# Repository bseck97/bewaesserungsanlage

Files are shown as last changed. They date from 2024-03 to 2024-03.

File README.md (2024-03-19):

# Automatische Bewässerungsanlage

## Beschreibung

Automatische Bewässerungsanlage bestehend aus einer Basisstation mit einem ESP32 und kapazitiven Bodenfeuchtesensoren.

Die Bewässerungsanlage ist im Rahmen eines Masterprojekts der [Hochschule Heilbronn](https://www.hs-heilbronn.de/) entstanden. Die Entwicklung und die Messungen fanden im Labor für Elektronische Schaltungstechnik statt. 

Für weitere Informationen wird auf die [Dokumentation](./dokumentation.pdf) verwiesen. 

## Dateistruktur

- basisstation - ESP-IDF Projekt für die Basisstation
- sensor - STM32CubeMX Projekt für den Sensor
- sensor_pcb - EAGLE Projekt für das Sensorboard

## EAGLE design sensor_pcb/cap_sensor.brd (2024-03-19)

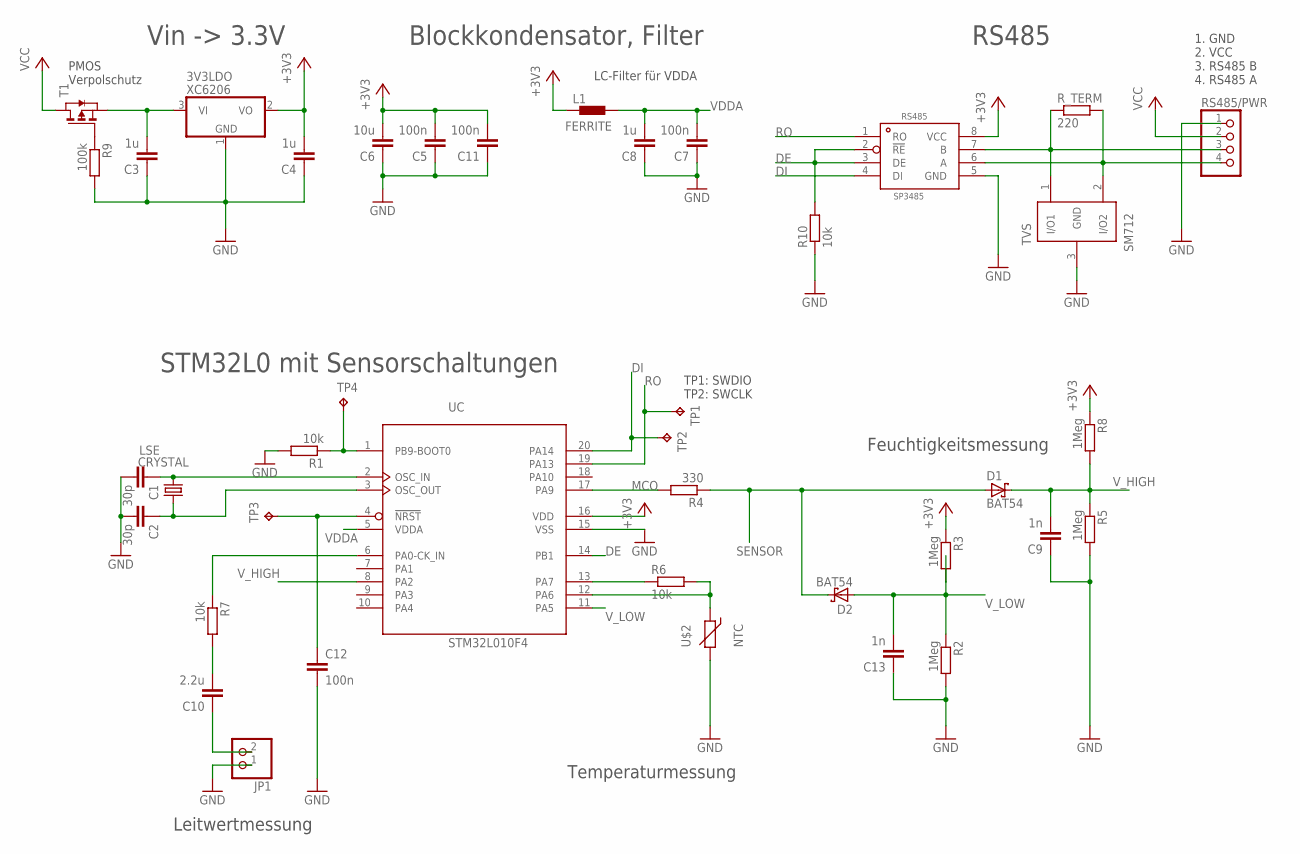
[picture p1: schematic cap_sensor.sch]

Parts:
3V3LDO: XC6206; SOT23-3
C1, C2: 30p; C0603
C3, C4, C8: 1u; C0603
C5, C7, C11, C12: 100n; C0603
C6: 10u; C0603
C9, C13: 1n; C0603
C10: 2.2u; C0603
D1, D2: BAT54; SOT23
JP1: PINHD-1X2; 1X02
L1: FERRITE; R0603
LSE: CRYSTAL; CRYSTAL-3.2X1.5
R1, R6, R7, R10: 10k; R0603
R2, R3, R5, R8: 1Meg; R0603
R4: 330; R0603
R9: 100k; R0603
RS485: SP3485; NSOIC8
RS485/PWR: PINHD-1X4; 1X04
R_TERM: 220; R0603
T1: PMOSSOT23; SOT-23
TP1, TP2, TP3, TP4: TPTP12R; TP12R
TVS: SM712; SOT23-3
U$2: NTC; R0603
UC: STM32L010F4; TSSOP20-I

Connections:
+3V3: 3V3LDO.2 (VO), C4.2, C5.2, C6.2, C11.2, L1.1, R3.1, R8.1, RS485.8 (VCC), UC.16 (VDD)
DE: R10.2, RS485.2 (!RE), RS485.3 (DE), UC.14 (PB1)
DI: RS485.4 (DI), TP2.TP, UC.20 (PA14)
GND: 3V3LDO.1 (GND), C1.2, C2.2, C3.1, C4.1, C5.1, C6.1, C7.1, C8.1, C9.1, C11.1, C12.2, C13.1, JP1.1, R1.2, R2.2, R5.2, R9.2, R10.1, RS485.5 (GND), RS485/PWR.1, TVS.3 (GND), U$2.2, UC.15 (VSS)
MCO: R4.2, UC.17 (PA9)
unnamed: 3V3LDO.3 (VI), C3.2, T1.2 (S)
unnamed: R1.1, TP4.TP, UC.1 (PB9-BOOT0)
unnamed: R6.1, UC.13 (PA7)
unnamed: C10.1, JP1.2
unnamed: C10.2, R7.2
unnamed: R6.2, U$2.1, UC.12 (PA6)
unnamed: C12.1, TP3.TP, UC.4 (!NRST)
unnamed: C1.1, LSE.1, UC.2 (OSC_IN)
unnamed: C2.1, LSE.2, UC.3 (OSC_OUT)
unnamed: R9.1, T1.3 (G)
unnamed: RS485.7 (B), RS485/PWR.3, R_TERM.1, TVS.1 (I/O1)
unnamed: RS485.6 (A), RS485/PWR.4, R_TERM.2, TVS.2 (I/O2)
RO: RS485.1 (RO), TP1.TP, UC.19 (PA13)
SENSOR: D1.1 (A), D2.3 (C), R4.1
SENS_RES: R7.1, UC.6 (PA0-CK_IN)
VCC: RS485/PWR.2, T1.1 (D)
VDDA: C7.2, C8.2, L1.2, UC.5 (VDDA)
V_HIGH: C9.2, D1.3 (C), R5.1, R8.2, UC.8 (PA2)
V_LOW: C13.2, D2.1 (A), R2.1, R3.2, UC.11 (PA5)

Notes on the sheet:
LC-Filter für VDDA
TP1: SWDIO TP2: SWCLK
PMOS Verpolschutz
Blockkondensator, Filter
Leitwertmessung
Feuchtigkeitsmessung
Temperaturmessung
Vin -> 3.3V
RS485
STM32L0 mit Sensorschaltungen
1. GND 2. VCC 3. RS485 B 4. RS485 A

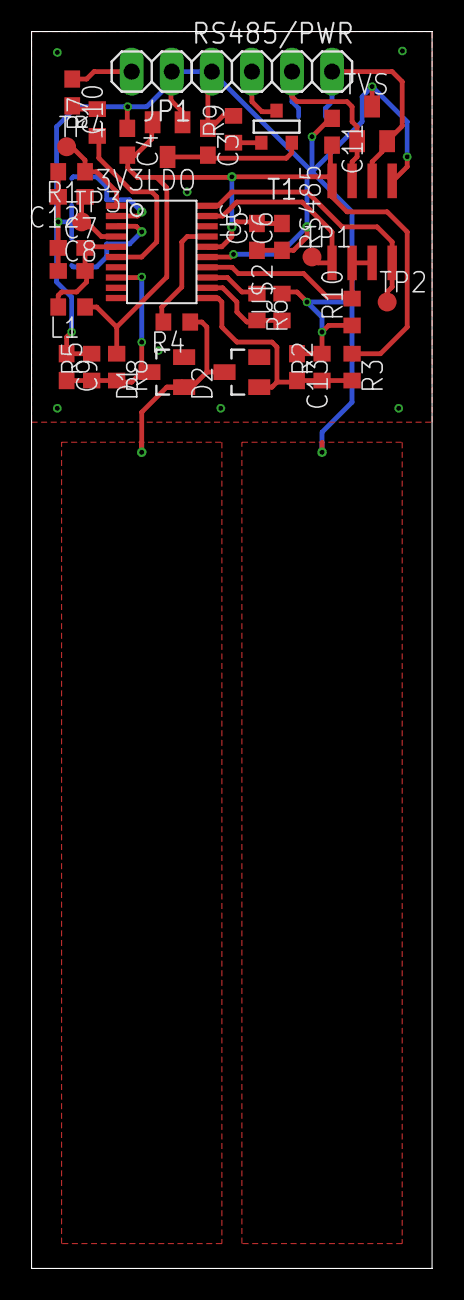
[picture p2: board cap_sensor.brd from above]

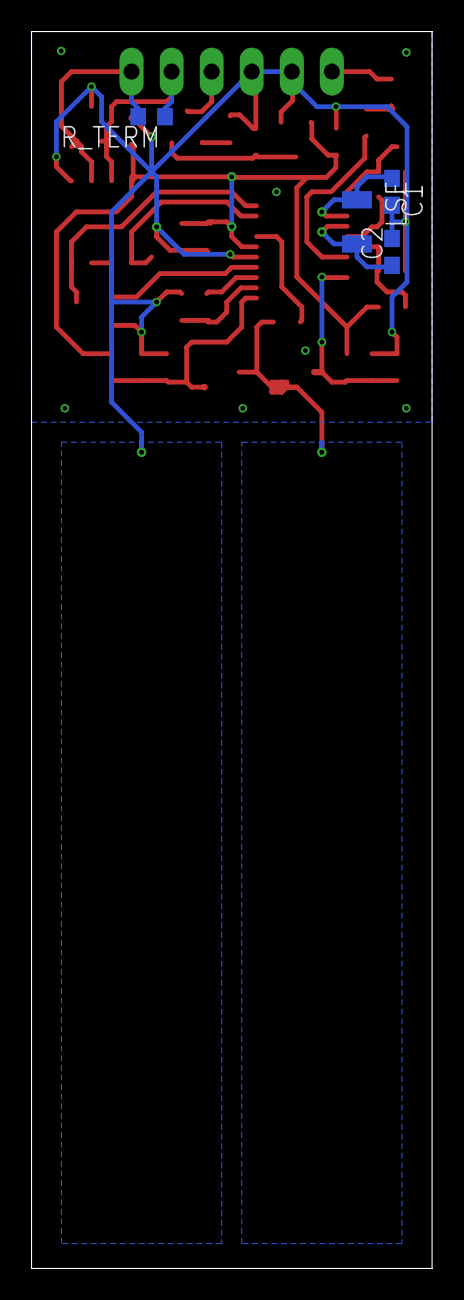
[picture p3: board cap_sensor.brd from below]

Board: 2 copper layers, 25.4 x 78.4 mm, 40 parts (4 on the bottom side), 24 nets.

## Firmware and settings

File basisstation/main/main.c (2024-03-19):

#include "driver/uart.h"
#include "esp_log.h"
#include "esp_system.h"
#include "esp_vfs_fat.h"
#include "freertos/FreeRTOS.h"
#include "freertos/queue.h"
#include "freertos/task.h"
#include "nvs_flash.h"
#include "sdkconfig.h"
#include "sdmmc_cmd.h"
#include <stdio.h>
#include <stdlib.h>
#include <string.h>
#include <sys/stat.h>
#include <sys/unistd.h>
// WIFI
#include "esp_event.h"
#include "esp_wifi.h"
#include "freertos/event_groups.h"
#include "lwip/err.h"
#include "lwip/sys.h"
#include "nvs_flash.h"
// NTP Time
#include "esp_sntp.h"
#include "time.h"
// timer
#include "esp_timer.h"
// MQTT
#include "cJSON.h"
#include "mqtt_client.h"
// steinhart-hart
#include <math.h>

#define TAG "ESP32_BASIS"

/* MQTT */
#define MQTT_URI "mqtt://MQTT_HOST_IP"
// topics
#define SENSOR_DATA "/topic/sensor"
#define DEBUG_MSG "/topic/debug"
#define THRESHOLD_TOPIC "/topic/threshold"
#define SENSOR_COUNT_TOPIC "/topic/sensor_count"
#define SENSOR_THRESHOLD_TOPIC "/topic/sensor_threshold"
#define PUMP_ON_TIME_TOPIC "/topic/pump_on_time"
#define PUMP_ON_TOPIC "/topic/pump_on"
#define SEND_ID_DELAY_TOPIC "/topic/send_id_delay"
#define TX_TASK_DELAY_TOPIC "/topic/tx_task_delay"
#define SENSOR_DATA_TOPIC "/topic/sensor_data"

esp_mqtt_client_handle_t client;
bool mqtt_connected = false; // flag to check if mqtt is connected

/* WIFI */
#define WIFI_SSID "YOUR_WIFI_SSID"
#define WIFI_PASSWORD "YOUR_WIFI_PASSWORD"

static EventGroupHandle_t
    s_wifi_event_group; // FreeRTOS event group to signal when we are connected
static int s_retry_num = 0;     // number of retries to connect to wifi
#define WIFI_CONNECTED_BIT BIT0 // connected to the AP with an IP
#define WIFI_FAIL_BIT                                                          \
  BIT1 // failed to connect after the maximum amount of retries

/* SD CARD */
#define MOUNT_POINT "/sdcard"
#define FILE_NAME MOUNT_POINT "/data.txt"

#define PIN_NUM_MISO 19
#define PIN_NUM_MOSI 23
#define PIN_NUM_CLK 18
#define PIN_NUM_CS 5

/* UART */
#define TXD 17
#define RXD 16
#define RTS 4
#define CTS -1 // CTS is not used in RS485 Half-Duplex Mode

#define DATA_LENGTH 20
#define RX_BUF_SIZE (127)
#define BAUD_RATE 115200
#define UART_PORT 2
// Read packet timeout
#define PACKET_READ_TICS (1000 / portTICK_PERIOD_MS)
// Timeout threshold for UART = number of symbols (~10 tics) with unchanged
// state on receive pin
#define READ_TOUT (3) // 3.5T * 8 = 28 ticks, TOUT=3 -> ~24..33 ticks

/* CONSTANTS AND OTHER CONFIG DATA */
#define LOG_TO_SD_CARD 1 // 1 to log data to SD card, 0 to disable
#define INIT_WIFI 1      // 1 to initialize wifi, 0 to disable
#define STACK_SIZE (2048)
#define REFERENCE_VOLTAGE 3.3
#define MAX_SENSORS 5
#define GPIO_PUMP 21           // GPIO to control relais
#define SECOND_US 1000000      // in microseconds
#define MINUTE_US 60 * 1000000 // in microseconds
#define MINUTE_MS 60 * 1000    // in milliseconds

// config vars, can be modified over MQTT
typedef struct {
  double threshold;
  int sensor_threshold;
  int sensor_count;
  int pump_on_time;
  int send_id_delay;
  int tx_task_delay;
} Config;

Config config = {
    .threshold = 2.0, // threshold after which the pump is turned on
    .sensor_threshold =
        2, // number of sensors that need to be above threshold to turn on pump
    .sensor_count = 3,             // number of sensors connected to the ESP32
    .pump_on_time = 5 * SECOND_US, // in microseconds, 5 seconds
    .send_id_delay = 3000,         // delay between sending IDs in ms (3s)
    .tx_task_delay =
        10 *
        MINUTE_MS // delay after another measurement set is taken in ms (10min)
};

// sensor data
typedef struct {
  uint32_t ID;
  double resistance_measurement_voltage;
  double V_HIGH_voltage;
  double V_LOW_voltage;
  double temperature;
} SensorData;

// history of sensor readings
typedef struct {
  SensorData current;
  SensorData previous1;
  SensorData previous2;
} SensorHistory;

SensorHistory
    sensorHistories[MAX_SENSORS]; // global var, all fields are init as 0

// timer to control pump on time
esp_timer_handle_t on_timer;

// task handles
TaskHandle_t rx_task_handle;
TaskHandle_t tx_task_handle;
TaskHandle_t sensordata_task_handle;

/* Function prototypes */
void uart_init(void);
void sd_card_init(void);
void initialize_sntp(void);
void wifi_init_sta(void);
void mqtt_init(void);

static void event_handler(void *arg, esp_event_base_t event_base,
                          int32_t event_id, void *event_data);
static void mqtt_event_handler(void *handler_args, esp_event_base_t base,
                               int32_t event_id, void *event_data);
static void on_timer_callback(void *arg);

esp_err_t send_ID(const int port, uint32_t id);
SensorData Convert_Bytes_to_Decimal(uint8_t *data);
double v_to_temp(double v_ntc);
char *sensor_data_to_json(const SensorData *data, bool include_time);
void write_to_sd_card(SensorData data);

static void tx_task(void *arg);
static void rx_task(void *arg);
static void sensordata_task(void *arg);

void app_main(void) {
  // create timer to turn off pump after pump_on_time
  const esp_timer_create_args_t on_timer_args = {.callback = &on_timer_callback,
                                                 .name = "on-timer"};
  ESP_ERROR_CHECK(esp_timer_create(&on_timer_args, &on_timer));

  // set PUMP GPIO to output
  gpio_set_direction(GPIO_PUMP, GPIO_MODE_OUTPUT);
  // set GPIO to LOW and turn off pump during init
  // in case the pump was on before restart
  gpio_set_level(GPIO_PUMP, 0);

  // check if INIT_WIFI is true, if not skip init
  if (INIT_WIFI) {
    // Initialize NVS, needed for WiFi
    esp_err_t ret = nvs_flash_init();
    if (ret == ESP_ERR_NVS_NO_FREE_PAGES ||
        ret == ESP_ERR_NVS_NEW_VERSION_FOUND) {
      ESP_ERROR_CHECK(nvs_flash_erase());
      ret = nvs_flash_init();
    }
    ESP_ERROR_CHECK(ret);

    wifi_init_sta();

    // if successfully connected, initialize SNTP and MQTT
    if (s_wifi_event_group != NULL) {
      if (xEventGroupGetBits(s_wifi_event_group) & WIFI_CONNECTED_BIT) {
        initialize_sntp();
        mqtt_init();
      }
    }
  }

  // check if LOG_TO_SD_CARD is true, if not skip init
  if (LOG_TO_SD_CARD) {
    sd_card_init();
  }

  uart_init();

  // wait a bit before starting the tasks
  vTaskDelay(2000 / portTICK_PERIOD_MS);

  // rx task gets double the default stack size, since fprintf uses a lot of
  // stack space
  xTaskCreate(rx_task, "uart_rx_task", STACK_SIZE * 2, NULL,
              configMAX_PRIORITIES, &rx_task_handle);
  xTaskCreate(tx_task, "uart_tx_task", STACK_SIZE, NULL,
              configMAX_PRIORITIES - 1, &tx_task_handle);
  xTaskCreate(sensordata_task, "sensordata_task", STACK_SIZE, NULL,
              configMAX_PRIORITIES - 2, &sensordata_task_handle);

  // this part is commented out by default, but can be used to check the stack
  // size of the tasks
  /*
  while (1)
  {
      UBaseType_t uxHighWaterMark = uxTaskGetStackHighWaterMark(rx_task_handle);
      ESP_LOGI(TAG, "Minimum free stack size for rx_task: %u", uxHighWaterMark);

      uxHighWaterMark = uxTaskGetStackHighWaterMark(tx_task_handle);
      ESP_LOGI(TAG, "Minimum free stack size for tx_task: %u", uxHighWaterMark);

      uxHighWaterMark = uxTaskGetStackHighWaterMark(sensordata_task_handle);
      ESP_LOGI(TAG, "Minimum free stack size for sensor readings task: %u",
  uxHighWaterMark);

      vTaskDelay(3000 / portTICK_PERIOD_MS);
  }
  */
}

static void on_timer_callback(void *arg) {
  // this is called after the timer expires
  // turn off pump
  gpio_set_level(GPIO_PUMP, 0); // Set GPIO to LOW
}

static void event_handler(void *arg, esp_event_base_t event_base,
                          int32_t event_id, void *event_data) {
  // wifi event handler
  if (event_base == WIFI_EVENT && event_id == WIFI_EVENT_STA_START) {
    esp_wifi_connect();
  } else if (event_base == WIFI_EVENT &&
             event_id == WIFI_EVENT_STA_DISCONNECTED) {
    if (s_retry_num < 5) {
      esp_wifi_connect();
      s_retry_num++;
      ESP_LOGI(TAG, "Retry to connect to the AP");
    } else {
      xEventGroupSetBits(s_wifi_event_group, WIFI_FAIL_BIT);
    }
    ESP_LOGI(TAG, "Connect to the AP fail");
  } else if (event_base == IP_EVENT && event_id == IP_EVENT_STA_GOT_IP) {
    ip_event_got_ip_t *event = (ip_event_got_ip_t *)event_data;
    ESP_LOGI(TAG, "Got IP:" IPSTR, IP2STR(&event->ip_info.ip));
    s_retry_num = 0;
    xEventGroupSetBits(s_wifi_event_group, WIFI_CONNECTED_BIT);
  }
}

static void mqtt_event_handler(void *handler_args, esp_event_base_t base,
                               int32_t event_id, void *event_data) {
  ESP_LOGD(TAG,
           "Event dispatched from event loop base=%s, event_id=%" PRIi32 "",
           base, event_id);
  esp_mqtt_event_handle_t event = event_data;
  client = event->client;

  switch ((esp_mqtt_event_id_t)event_id) {
  case MQTT_EVENT_CONNECTED:
    ESP_LOGI(TAG, "MQTT_EVENT_CONNECTED");
    mqtt_connected = true;

    // subscribe to topics
    esp_mqtt_client_subscribe(client, THRESHOLD_TOPIC, 0);
    esp_mqtt_client_subscribe(client, SENSOR_COUNT_TOPIC, 0);
    esp_mqtt_client_subscribe(client, PUMP_ON_TIME_TOPIC, 0);
    esp_mqtt_client_subscribe(client, PUMP_ON_TOPIC, 0);
    esp_mqtt_client_subscribe(client, SEND_ID_DELAY_TOPIC, 0);
    esp_mqtt_client_subscribe(client, TX_TASK_DELAY_TOPIC, 0);
    esp_mqtt_client_subscribe(client, SENSOR_THRESHOLD_TOPIC, 0);
    esp_mqtt_client_subscribe(client, SENSOR_DATA_TOPIC, 0);

    break;
  case MQTT_EVENT_DISCONNECTED:
    ESP_LOGI(TAG, "MQTT_EVENT_DISCONNECTED");
    mqtt_connected = false;
    break;
  case MQTT_EVENT_SUBSCRIBED:
    ESP_LOGI(TAG, "MQTT_EVENT_SUBSCRIBED, msg_id=%d", event->msg_id);
    break;
  case MQTT_EVENT_UNSUBSCRIBED:
    ESP_LOGI(TAG, "MQTT_EVENT_UNSUBSCRIBED, msg_id=%d", event->msg_id);
    break;
  case MQTT_EVENT_PUBLISHED:
    ESP_LOGI(TAG, "MQTT_EVENT_PUBLISHED, msg_id=%d", event->msg_id);
    break;
  case MQTT_EVENT_DATA:
    ESP_LOGI(TAG, "MQTT_EVENT_DATA");
    printf("TOPIC=%.*s\r\n", event->topic_len, event->topic);
    printf("DATA=%.*s\r\n", event->data_len, event->data);

    // Null-terminate the topic and data strings for easy handling
    char *topic = malloc(event->topic_len + 1);
    memcpy(topic, event->topic, event->topic_len);
    topic[event->topic_len] = '\0';

    char *data = malloc(event->data_len + 1);
    memcpy(data, event->data, event->data_len);
    data[event->data_len] = '\0';

    // Update configuration variables based on the topic
    if (strcmp(topic, THRESHOLD_TOPIC) == 0) {
      config.threshold = atof(data);
      ESP_LOGI(TAG, "New threshold: %f", config.threshold);
      esp_mqtt_client_publish(client, DEBUG_MSG, "threshold_updated", 0, 0, 0);
    } else if (strcmp(topic, PUMP_ON_TIME_TOPIC) == 0) {
      config.pump_on_time = atoi(data);
      ESP_LOGI(TAG, "New pump on time: %d", config.pump_on_time);
      esp_mqtt_client_publish(client, DEBUG_MSG, "pump_on_time_updated", 0, 0,
                              0);
    } else if (strcmp(topic, PUMP_ON_TOPIC) == 0) {
      gpio_set_level(GPIO_PUMP, 1);
      // Try to start the on_timer
      esp_err_t ret = esp_timer_start_once(on_timer, config.pump_on_time);
      if (ret != ESP_OK) {
        gpio_set_level(GPIO_PUMP, 0); // Turn off the pump immediately
        char error_message[100];      // Buffer for the error message
        snprintf(error_message, sizeof(error_message),
                 "Failed to start on_timer with error %d", ret);
        ESP_LOGE(TAG, "%s", error_message);

        // Publish the error via MQTT
        esp_mqtt_client_publish(client, DEBUG_MSG, error_message, 0, 0, 0);
      } else {
        esp_mqtt_client_publish(client, DEBUG_MSG, "pump_on", 0, 0, 0);
      }
    } else if (strcmp(topic, SENSOR_COUNT_TOPIC) == 0) {
      config.sensor_count = atoi(data);
      ESP_LOGI(TAG, "New sensor count: %d", config.sensor_count);
      esp_mqtt_client_publish(client, DEBUG_MSG, "sensor_count_updated", 0, 0,
                              0);
    } else if (strcmp(topic, SEND_ID_DELAY_TOPIC) == 0) {
      config.send_id_delay = atoi(data);
      ESP_LOGI(TAG, "New send id delay: %d", config.send_id_delay);
      esp_mqtt_client_publish(client, DEBUG_MSG, "send_id_delay_updated", 0, 0,
                              0);
    } else if (strcmp(topic, TX_TASK_DELAY_TOPIC) == 0) {
      config.tx_task_delay = atoi(data);
      ESP_LOGI(TAG, "New tx task delay: %d", config.tx_task_delay);
      esp_mqtt_client_publish(client, DEBUG_MSG, "tx_task_delay_updated", 0, 0,
                              0);
    } else if (strcmp(topic, SENSOR_THRESHOLD_TOPIC) == 0) {
      config.sensor_threshold = atoi(data);
      ESP_LOGI(TAG, "New sensor threshold: %d", config.sensor_threshold);
      esp_mqtt_client_publish(client, DEBUG_MSG, "sensor_threshold_updated", 0,
                              0, 0);
    } else if (strcmp(topic, SENSOR_DATA_TOPIC) == 0) {
      uint32_t sensor_id = atoi(data); // Parse the sensor ID from the data

      // Find the corresponding sensor data
      for (int i = 0; i < MAX_SENSORS; i++) {
        if (sensorHistories[i].current.ID == sensor_id) {
          // Convert the sensor data to JSON and publish it
          char *json = sensor_data_to_json(&sensorHistories[i].current, false);
          esp_mqtt_client_publish(client, SENSOR_DATA, json, 0, 0, 0);
          free(json);
          break;
        }
      }
    }

    free(topic);
    free(data);
    break;
  case MQTT_EVENT_ERROR:
    ESP_LOGI(TAG, "MQTT_EVENT_ERROR");
    break;
  default:
    ESP_LOGI(TAG, "Other event id:%d", event->event_id);
    break;
  }
}

// Function to convert sensor data to JSON
char *sensor_data_to_json(const SensorData *data, bool include_time) {
  cJSON *json = cJSON_CreateObject();

  // Add time to JSON if requested
  if (include_time) {
    wifi_ap_record_t info;
    if (esp_wifi_sta_get_ap_info(&info) == ESP_OK) {
      // Get current time
      time_t now;
      struct tm timeinfo;
      time(&now);
      localtime_r(&now, &timeinfo);

      char time_str[30];
      strftime(time_str, sizeof(time_str), "%FT%T",
               &timeinfo); // Convert timeinfo to ISO 8601 format
      cJSON_AddStringToObject(json, "Date and Time", time_str);
    } else {
      // Get time since boot
      int64_t time_since_boot = esp_timer_get_time();
      cJSON_AddNumberToObject(json, "Time since boot", time_since_boot);
    }
  }

  cJSON_AddNumberToObject(json, "ID", data->ID);
  cJSON_AddNumberToObject(json, "Resistance Measurement (V)",
                          data->resistance_measurement_voltage);
  cJSON_AddNumberToObject(json, "V_HIGH (V)", data->V_HIGH_voltage);
  cJSON_AddNumberToObject(json, "V_LOW (V)", data->V_LOW_voltage);
  cJSON_AddNumberToObject(json, "Temperature (C)", data->temperature);

  char *string = cJSON_Print(json);
  cJSON_Delete(json);
  return string;
}

// Function to write sensor data to SD card
void write_to_sd_card(SensorData data) {
  FILE *f = fopen(FILE_NAME, "a");
  if (f == NULL) {
    char error_message[100]; // Buffer for the error message
    snprintf(error_message, sizeof(error_message),
             "Failed to open file for writing");
    ESP_LOGE(TAG, "%s", error_message);

    // Publish the error via MQTT
    if (mqtt_connected) {
      esp_mqtt_client_publish(client, DEBUG_MSG, error_message, 0, 0, 0);
    }

    return;
  }

  // Convert sensor data to JSON
  char *json_data = sensor_data_to_json(&data, true);

  // Print sensor data to file
  fprintf(f, "%s\n", json_data); // insert JSON data
  free(json_data);               // Don't forget to free the JSON string

  if (fclose(f) != 0) {
    char error_message[100]; // Buffer for the error message
    snprintf(error_message, sizeof(error_message), "Failed to close file");
    ESP_LOGE(TAG, "%s", error_message);

    // Publish the error via MQTT
    if (mqtt_connected) {
      esp_mqtt_client_publish(client, DEBUG_MSG, error_message, 0, 0, 0);
    }

    return;
  }

  ESP_LOGI(TAG, "Data written to SD card\n");
  // send mqtt msg that write to sd card was successful
  if (mqtt_connected) {
    esp_mqtt_client_publish(client, DEBUG_MSG, "sd_card_write_successful", 0, 0,
                            0);
  }
}

// Function to send the sensor ID to request data
esp_err_t send_ID(const int port, uint32_t id) {
  uint8_t data[4];
  data[0] = id & 0xFF; // LSB
  data[1] = (id >> 8) & 0xFF;
  data[2] = (id >> 16) & 0xFF;
  data[3] = (id >> 24) & 0xFF; // MSB

  int write_bytes = uart_write_bytes(port, (const char *)data, sizeof(data));

  if (write_bytes != sizeof(data)) {
    ESP_LOGE(TAG, "Send data critical failure.");
    return ESP_FAIL; // Return an error code
  }
  return ESP_OK; // Return success code
}

// Function to convert measured voltage to temperature using the Steinhart-Hart
// equation
double v_to_temp(double v_ntc) {
  // Steinhart-Hart Coefficients
  // source: https://www.vishay.com/en/thermistors/ntc-rt-calculator/
  // and:
  // https://www.thinksrs.com/downloads/programs/therm%20calc/ntccalibrator/ntccalculator.html
  const double A = 1.081730263e-3;
  const double B = 2.156147549e-4;
  const double C = 3.665619003e-7;

  // Fixed resistor value used in voltage divider
  const double R = 10000.0;
  // Calculate the resistance of the NTC
  double R_ntc = v_ntc / ((REFERENCE_VOLTAGE - v_ntc) / R);

  // Calculate the temperature using the Steinhart-Hart equation
  double lnR = log(R_ntc);
  double T = 1.0 / (A + B * lnR + C * pow(lnR, 3));

  // Convert from Kelvin to Celsius
  T = T - 273.15;

  return T;
}

SensorData Convert_Bytes_to_Decimal(uint8_t *data) {
  SensorData sensorData;

  uint32_t ID;

  // Discard erroneous bytes at the beginning, if any
  // this loop increments the pointer at most 12 times until it finds a valid ID
  for (int i = 0; i < 12; i++) {
    ID = (data[3] << 24) | (data[2] << 16) | (data[1] << 8) | data[0];

    // if ID is a valid value, convert bytes to decimal
    if (ID >= 10000 && ID <= (10000 + config.sensor_count)) {
      uint32_t resistance_measurement =
          (data[7] << 24) | (data[6] << 16) | (data[5] << 8) | data[4];
      uint32_t V_HIGH =
          (data[11] << 24) | (data[10] << 16) | (data[9] << 8) | data[8];
      uint32_t V_LOW =
          (data[15] << 24) | (data[14] << 16) | (data[13] << 8) | data[12];
      uint32_t temperature_adc =
          (data[19] << 24) | (data[18] << 16) | (data[17] << 8) | data[16];

      // calc voltage values

      double const ADC_MAX_VALUE = 4095;

      double resistance_measurement_voltage =
          (resistance_measurement / ADC_MAX_VALUE) * REFERENCE_VOLTAGE;
      double V_HIGH_voltage = (V_HIGH / ADC_MAX_VALUE) * REFERENCE_VOLTAGE;
      double V_LOW_voltage = (V_LOW / ADC_MAX_VALUE) * REFERENCE_VOLTAGE;
      double temperature_voltage =
          (temperature_adc / ADC_MAX_VALUE) * REFERENCE_VOLTAGE;

      // convert voltage to temperature
      double temperature_c = v_to_temp(temperature_voltage);

      // save data to sensor history
      SensorHistory *history = &sensorHistories[ID - 10000];
      history->previous2 = history->previous1;
      history->previous1 = history->current;
      history->current.ID = ID;
      history->current.resistance_measurement_voltage =
          resistance_measurement_voltage;
      history->current.V_HIGH_voltage = V_HIGH_voltage;
      history->current.V_LOW_voltage = V_LOW_voltage;
      history->current.temperature = temperature_c;

      // save data to struct and return
      sensorData.ID = ID;
      sensorData.resistance_measurement_voltage =
          resistance_measurement_voltage;
      sensorData.V_HIGH_voltage = V_HIGH_voltage;
      sensorData.V_LOW_voltage = V_LOW_voltage;
      sensorData.temperature = temperature_c;

      return sensorData;
    }

    data++;
  }

  // if the function didnt return yet, the ID is not valid
  ESP_LOGE(TAG, "ID is not valid");
  sensorData.ID = 0;
  return sensorData;
}

// Init functions
void uart_init(void) {
  // Configure parameters of UART
  // 8 Databits, keine Parität, 1 Stopbit
  uart_config_t uart_config = {
      .baud_rate = BAUD_RATE,
      .data_bits = UART_DATA_8_BITS,
      .parity = UART_PARITY_DISABLE,
      .stop_bits = UART_STOP_BITS_1,
      .flow_ctrl = UART_HW_FLOWCTRL_DISABLE,
      .rx_flow_ctrl_thresh = 122,
      .source_clk = UART_SCLK_DEFAULT,
  };

  ESP_LOGI(TAG, "Start application and configure UART.");

  // Install UART driver (we don't need an event queue here)
  ESP_ERROR_CHECK(
      uart_driver_install(UART_PORT, RX_BUF_SIZE * 2, 0, 0, NULL, 0));

  // Configure UART parameters
  ESP_ERROR_CHECK(uart_param_config(UART_PORT, &uart_config));

  // Set UART pins
  ESP_ERROR_CHECK(uart_set_pin(UART_PORT, TXD, RXD, RTS, CTS));

  // Set RS485 half duplex mode
  ESP_ERROR_CHECK(uart_set_mode(UART_PORT, UART_MODE_RS485_HALF_DUPLEX));

  // Set read timeout of UART TOUT feature
  ESP_ERROR_CHECK(uart_set_rx_timeout(UART_PORT, READ_TOUT));
}
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

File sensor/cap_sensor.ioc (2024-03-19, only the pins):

Mcu.UserName=STM32L010F4Px
PA0-CK_IN.Signal=ADC_IN0
PA13.Signal=LPUART1_RX
PA14.Signal=LPUART1_TX
PA2.Signal=ADC_IN2
PA5.Signal=ADC_IN5
PA6.Signal=ADC_IN6
PA7.Signal=GPIO_Output
PA9.Signal=RCC_MCO
PB1.Signal=LPUART1_DE

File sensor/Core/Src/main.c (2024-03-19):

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
/* Includes ------------------------------------------------------------------*/
#include "main.h"

/* USER CODE BEGIN Includes */
#include <string.h>
#include <stdio.h>
/* USER CODE END Includes */

/* USER CODE BEGIN PD */
#define ID 10000
/* USER CODE END PD */

ADC_HandleTypeDef hadc;

UART_HandleTypeDef hlpuart1;

/* USER CODE BEGIN PV */
UART_WakeUpTypeDef WakeUpSelection;

uint8_t RXData[4]; // Buffer to store received data
uint32_t TXData[5]; // Buffer to store data to send
/* USER CODE END PV */

void SystemClock_Config(void);
static void MX_GPIO_Init(void);
static void MX_ADC_Init(void);
static void MX_LPUART1_UART_Init(void);
/* USER CODE BEGIN 0 */
uint32_t Poll_ADC_Channel()
{
  // Start ADC Conversion
  HAL_ADC_Start(&hadc);

  // Poll for ADC conversion
  if (HAL_ADC_PollForConversion(&hadc, 10) == HAL_OK)
  {
    uint32_t ADC_Value = HAL_ADC_GetValue(&hadc);
    return ADC_Value;
  }

  // Stop ADC Conversion
  HAL_ADC_Stop(&hadc);

  return 0; // Return 0 if there was an error
}

void Measure_And_Transmit()
{
	// declare buffer to send data
	uint32_t TXData[5];

	// first, include ID
	TXData[0] = ID;

	// Configure PA0 as Output and Set it High
	LL_GPIO_SetOutputPin(GPIOA, LL_GPIO_PIN_0);
	LL_GPIO_SetPinMode(GPIOA, LL_GPIO_PIN_0, LL_GPIO_MODE_OUTPUT);

	// charge cap for 50ms
	HAL_Delay(50);

	// Configure as ADC
	LL_GPIO_SetPinMode(GPIOA, LL_GPIO_PIN_0, LL_GPIO_MODE_ANALOG);

	// wait 2ms to give the voltage time to stabilize
	HAL_Delay(2);

	// Measure the voltage on PA0
	TXData[1] = Poll_ADC_Channel();

	// Delay for another 8ms to be able to inspect the signal on an oscilloscope
	HAL_Delay(8);

	// Manually set PA0 LOW to discharge the capacitor
	LL_GPIO_ResetOutputPin(GPIOA, LL_GPIO_PIN_0);
	LL_GPIO_SetPinMode(GPIOA, LL_GPIO_PIN_0, LL_GPIO_MODE_OUTPUT);

	// measure voltage on PA2 (V_HIGH)
	TXData[2] = Poll_ADC_Channel();

	// measure voltage on PA5 (V_LOW)
	TXData[3] = Poll_ADC_Channel();

	// Set PA7 high (Input R6)
	LL_GPIO_SetOutputPin(GPIOA, LL_GPIO_PIN_7);

	// Delay for 10ms
	HAL_Delay(10);

	// Read ADC_CHANNEL_6 (Output Spannungsteiler NTC - R6 10k)
	// NTC = Heissleiter, Spannung sinkt bei steigender Temp
	TXData[4] = Poll_ADC_Channel();

	// Set PA7 low
	LL_GPIO_ResetOutputPin(GPIOA, LL_GPIO_PIN_7);

	// Transmit sensor data
	HAL_UART_Transmit(&hlpuart1, (uint8_t*)&TXData, sizeof(TXData), 10000);
}
/* USER CODE END 0 */

/**
  * @brief  The application entry point.
  * @retval int
  */
int main(void)
{
  /* MCU Configuration--------------------------------------------------------*/

  /* Reset of all peripherals, Initializes the Flash interface and the Systick. */
  HAL_Init();

  /* Configure the system clock */
  SystemClock_Config();

  /* Initialize all configured peripherals */
  MX_GPIO_Init();
  MX_ADC_Init();
  MX_LPUART1_UART_Init();
  /* Infinite loop */
  /* USER CODE BEGIN WHILE */

  while (1)
  {
    // wait 10s for data to be received
	if (HAL_UART_Receive(&hlpuart1, RXData, sizeof(RXData), 2000) == HAL_OK) {
		// Convert received data to ID
		uint32_t received_id = (RXData[0]) | (RXData[1] << 8) | (RXData[2] << 16) | (RXData[3] << 24);
		if (received_id == ID) {
			Measure_And_Transmit();
		}
	}
    /* USER CODE END WHILE */

    /* USER CODE BEGIN 3 */
  }
  /*
  void SystemClock_Config(void)
  {
    ...
      while (LL_PWR_IsActiveFlag_VOS() != 0)
	  {
	  }
	..
	}
    */
  /* USER CODE END 3 */
}

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

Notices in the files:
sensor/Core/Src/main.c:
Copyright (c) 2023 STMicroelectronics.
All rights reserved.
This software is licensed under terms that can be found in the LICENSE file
